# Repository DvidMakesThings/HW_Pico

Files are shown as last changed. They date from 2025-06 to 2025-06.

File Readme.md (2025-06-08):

# RePico

RePico is a custom-designed, feature-enhanced Raspberry Pi Pico-compatible board built for serious embedded developers. It keeps full compatibility with the RP2040 ecosystem while upgrading key components for cleaner analog performance, improved configurability, and professional-grade layout.

<p align="center">
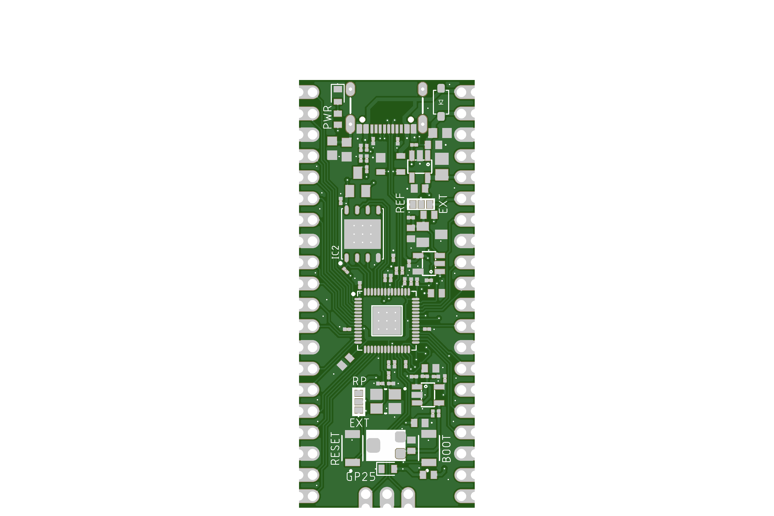
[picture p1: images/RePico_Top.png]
RePico Top
    
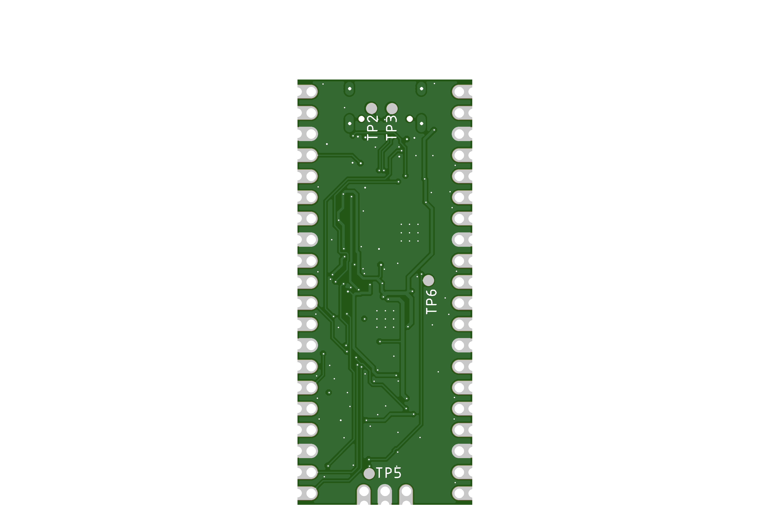
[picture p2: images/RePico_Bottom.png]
RePico Bottom
    
</p>

---

## 🔧 Key Hardware Features

- **USB-C** connector instead of Micro-USB for modern connectivity.
- **Low-noise 3.3V power supply** using `MIC5504-3.3YM5` 3.3V 300mA LDO (replaces noisy SMPS).
- **Selectable ADC Vref** via jumper:
  - External Vref input.
  - Internal precision 3.0V reference using `LM4040` + buffered by `MCP6001RT-I/OT`.
- **Selectable Vcore Supply** via jumper:
  - Use internal RP2040 regulator.
  - Or use onboard external 1.1V regulator based on `AP7335-WG-7` with adjustable output.
- **Adjustable Vcore Tuning** with trimpot-based feedback:

| Trimpot Resistance | Vcore Output |
|---|---|
| 25k (max) | ~1.00 V |
| 12.5k (mid) | ~1.18 V |
| 0 Ω (min) | ~1.24 V |

- **128Mbit (16MB) QSPI Flash** — 4x more than the standard Pico.
- **RESET** and **BOOT** buttons included onboard.
- **4-layer impedance-controlled PCB** for signal integrity.

---

## PCB Stackup

- **Total Layers:** 4
- **Finished Thickness:** ~1.56 mm ±10%
- **Outer Copper Weight:** 1 oz
- **Inner Copper Weight:** 0.5 oz
- **Material:** JLC04161H-3313 (FR4)

### Layer Stackup

| Layer | Description | Material | Thickness (mm) |
|---|---|---|---|
| L1 | Signal (Top) | Outer Copper 1 oz | 0.0350 |
| | Prepreg | 3313 RC57%, 4.2 mil | 0.0994 |
| L2 | Internal Plane | Inner Copper 0.5 oz | 0.0152 |
| | Core | 1.3 mm H/HOZ with copper | 1.2650 |
| L3 | Internal Plane | Inner Copper 0.5 oz | 0.0152 |
| | Prepreg | 3313 RC57%, 4.2 mil | 0.0994 |
| L4 | Signal (Bottom) | Outer Copper 1 oz | 0.0350 |
| | **Total Thickness** | | **1.5588 mm**  |

---

## 📏 Controlled Impedance Configuration

| Impedance (Ω) | Type | Signal Layer | Top Ref | Bottom Ref | Trace Width (mm) | Trace Spacing (mm) | Trace to Copper (mm) |
|---|---|---|---|---|---|---|---|
| 50 | Coplanar Single Ended | L1 | / | L2 | 0.1486 | / | 0.2032 |
| 90 | Coplanar Differential | L1 | / | L2 | 0.1488 | 0.1778 | 0.2032 |
| 90 | Coplanar Differential | L4 | L3 | / | 0.1488 | 0.1778 | 0.2032 |
| 50 | Coplanar Single Ended | L4 | L3 | / | 0.1486 | / | 0.2032 |

---

## 🧠 RP2040 Pinout Compatibility

All RP2040 GPIOs are exposed through 2.54mm castellated headers, maintaining full compatibility with the original Raspberry Pi Pico pinout. 

---

## Misc: Core Voltage & Overclocking

To overclock the MCU, it's possible to supply more than 1.1 V to the core.  
By default, **external core voltage generation** is enabled using the **AP7335-WG-7**, which is activated via **J1**.  
The output voltage is set by adjusting the **R1 trimpot**.

> ⚠️ It is safe — the voltage range is limited by design and cannot damage the MCU.

### Voltage Range (Set by Divider)

| R1 (Trimpot) | Total Resistance (R28 + R1) | VOUT (approx) |
|---|---|---|
| 25 kΩ (max)  | 47 kΩ | 1.02 V |
| 12.5 kΩ | 34.5 kΩ | 1.14 V |
| 0 Ω (min) | 22 kΩ | 1.22 V |

### Use Cases

- **Low Power Mode:** R1 = 25 kΩ → ~1.02 V  
- **Default / Safe:** R1 = 12.5 kΩ → ~1.14 V  
- **High Performance / Overclocking:** R1 = 0 Ω → ~1.22 V  

### VOUT Behavior Across Temperatures and Trim Settings

The AP7335-WG-7 regulator is affected by temperature-dependent reference voltage (VREF), output voltage accuracy, and resistor tolerances.  
This section outlines the **worst-case VOUT values** at cold, normal, and hot temperatures, across all trimpot settings.

> ⚙️ **Calculation Parameters:**
> - VOUT Accuracy: ±2% (from AP7335-WG-7 datasheet)
> - VREF Variation: Based on VREF vs. Temperature graph  
>   - −50 °C → 0.89 V  
>   - 25 °C → 0.80 V  
>   - 125 °C → 0.782 V
> - Resistors used: 1% tolerance (R27 = 12 kΩ, R28 = 22 kΩ, R1 = 0–25 kΩ trimpot)

The RP2040's **absolute maximum core voltage is 1.3 V** — values exceeding this may cause damage.

---

### ❄️ Cold (–50 °C, VREF = 0.89 V)

**Max Trim (R1 = 25 kΩ, Rb = 47 kΩ)**  
VOUT: **1.090 V – 1.144 V** ✅ Safe

**Mid Trim (R1 = 12.5 kΩ, Rb = 34.5 kΩ)**  
VOUT: **1.170 V – 1.230 V** ✅ Safe

**Min Trim (R1 = 0 Ω, Rb = 22 kΩ)**  
VOUT: **1.339 V – 1.413 V** ❌ Danger – exceeds RP2040 1.3 V limit

---

### 🌤️ Normal (25 °C, VREF = 0.80 V)

**Max Trim (R1 = 25 kΩ, Rb = 47 kΩ)**  
VOUT: **0.980 V – 1.029 V** ✅ Safe

**Mid Trim (R1 = 12.5 kΩ, Rb = 34.5 kΩ)**  
VOUT: **1.051 V – 1.106 V** ✅ Safe

**Min Trim (R1 = 0 Ω, Rb = 22 kΩ)**  
VOUT: **1.201 V – 1.265 V** ✅ Safe

---

### 🔥 Hot (125 °C, VREF = 0.782 V)

**Max Trim (R1 = 25 kΩ, Rb = 47 kΩ)**  
VOUT: **0.958 V – 1.005 V** ✅ Safe

**Mid Trim (R1 = 12.5 kΩ, Rb = 34.5 kΩ)**  
VOUT: **1.028 V – 1.082 V** ✅ Safe

**Min Trim (R1 = 0 Ω, Rb = 22 kΩ)**  
VOUT: **1.180 V – 1.243 V** ✅ Safe

## License
This project is licensed under the GPL-3.0 License. See the [LICENSE](LICENSE) file for details.

## Contact
For questions or feedback:
- Email: [dvidmakesthing@gmail.com](mailto:dvidmakesthing@gmail.com)
- GitHub: [DvidMakesThings](https://github.com/DvidMakesThings)

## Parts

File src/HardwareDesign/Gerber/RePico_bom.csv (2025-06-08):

Comment | Designator | Footprint | LCSC Part #
 | IC2 | SON127P600X500X75-8N
1K 1% | R4 | 0201 | C270365
1K 1% | R5 | 0201 | C270365
1K 1% | R20 | 0402 | C11702
1K 1% | R21 | 0402 | C11702
1M 1% | R14 | 0603 | C22935
1nF 25V | C27 | 0201 | C7694325V
1uF 25V | C32 | 0402 | C52923
2.2uF 25V | C8 | 0402 | C385032
2.2uF 25V | C10 | 0402 | C385032
4.7K 1% | R6 | 0402 | C25900
4.7nF 50V | C22 | 0603 | C53987
4.7uF 25V | C30 | 0402 | C22367824
4.7uF 25V | C31 | 0402 | C22367824
5.1K 1% | R12 | 0201 | C274341
5.1K 1% | R13 | 0201 | C274341
10K 1% | R1 | 0201 | C473048
10K 1% | R8 | 0201 | C473048
10K 1% | R16 | 0201 | C473048
10K 1% | R17 | 0201 | C473048
12K 1% | R9 | 0201 | C270363
12MHz | X1 | WE-XTAL_CFPX-180 | C9002
15pF 50V | C14 | 0201 | C22374851
15pF 50V | C15 | 0201 | C22374851
22K 1% | R10 | 0201 | C474416
22uF 10V | C23 | 0603 | C60077
27R 1% | R2 | 0201 | C473051
27R 1% | R3 | 0201 | C473051
47uF 10V | C24 | 0805 | C6119904
50K | R7 | SMD_TRIMM | C913246
50K 1% | R11 | 0402 | C166559
100K 1% | R15 | 0201 | C270364
100K 1% | R18 | 0201 | C270364
100nF 25V | C1 | 0201 | C76939
100nF 25V | C2 | 0201 | C76939
100nF 25V | C3 | 0201 | C76939
100nF 25V | C4 | 0201 | C76939
100nF 25V | C5 | 0201 | C76939
100nF 25V | C6 | 0201 | C76939
100nF 25V | C7 | 0201 | C76939
100nF 25V | C9 | 0201 | C76939
100nF 25V | C11 | 0201 | C76939
100nF 25V | C12 | 0201 | C76939
100nF 25V | C13 | 0201 | C76939
100nF 25V | C16 | 0201 | C76939
100nF 25V | C17 | 0201 | C76939
100nF 25V | C18 | 0201 | C76939
100nF 25V | C19 | 0201 | C76939
100nF 25V | C20 | 0201 | C76939
100nF 25V | C21 | 0201 | C76939
100nF 50V | C25 | 0402 | C307331
100nF 50V | C26 | 0402 | C307331
200K 1% | R19 | 0201 | C270357
AP7335-WG-7 | IC8 | SOT23-5 | C460382
B3U-1000P | BOOT | B3U-1000P | C231329
B3U-1000P | RESET | B3U-1000P | C231329
Blue | PWR | LED-0603 | C965807
DMG1012T | T1 | SOT23 | C2830301
DNI | J2 | R0201
Green | GP25 | LED-0603 | C965804
JUMPER-3 | J1 J3 | JUMPER-3
LM4040B30FTA | REF1 | SOT23 | C460604
MBR120VLSFT1G | D1 | SOD-123 | C223608
MCP6001RT-I/OT | IC5 | SOT23-5 | C154973
MIC5504-3.3YM5 | IC3 | SOT23-5 | C41348078
RP2040 | IC1 | QFN56 | C2040
SP0503BAHTG | ESD1 | SOT143 | C3040626
USB-TYPE-C-018 | USB1 | USB-C | C2927038
TPB1 27 | TP2 | B1 27
TPB1 27 | TP3 | B1 27
TPB1 27 | TP5 | B1 27
TPB1 27 | TP6 | B1 27

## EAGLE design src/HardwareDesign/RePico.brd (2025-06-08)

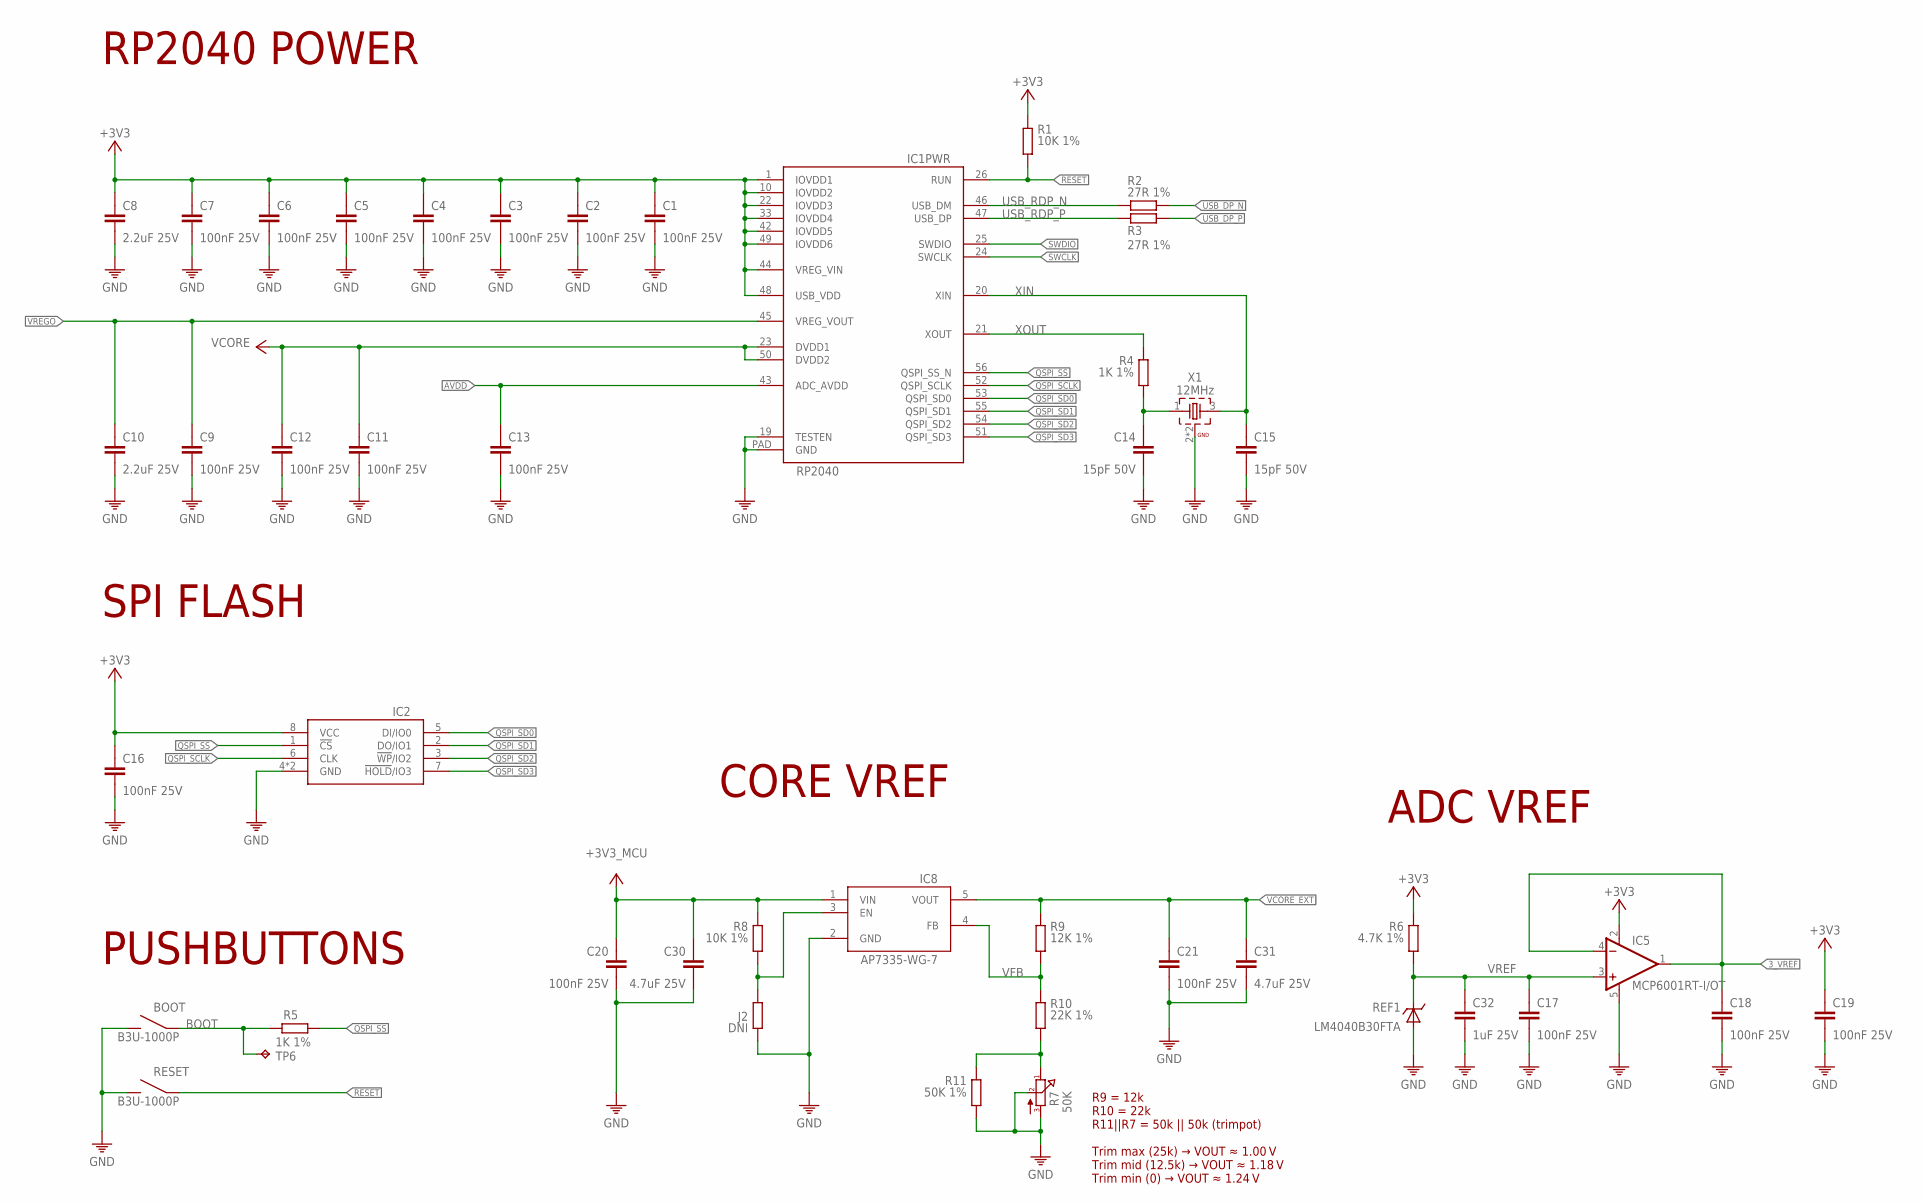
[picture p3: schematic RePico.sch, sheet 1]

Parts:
BOOT: B3U-1000P
C1, C2, C3, C4, C5, C6, C7, C9, C11, C12, C13, C16, C17, C18, C19, C20, C21: 100nF 25V; 0201
C8, C10: 2.2uF 25V; 0402
C14, C15: 15pF 50V; 0201
C30, C31: 4.7uF 25V; 0402
C32: 1uF 25V; 0402
IC1: RP2040; QFN56
IC2: W25Q128JVP; SON127P600X500X75-8N
IC5: MCP6001RT-I/OT; SOT23-5
IC8: AP7335-WG-7; SOT23-5
J2: DNI; R0201
R1, R8: 10K 1%; 0201
R2, R3: 27R 1%; 0201
R4, R5: 1K 1%; 0201
R6: 4.7K 1%; 0402
R7: 50K; SMD_TRIMM
R9: 12K 1%; 0201
R10: 22K 1%; 0201
R11: 50K 1%; 0402
REF1: LM4040B30FTA; SOT23
RESET: B3U-1000P
TP6: TPB1,27; B1,27
X1: 12MHz; WE-XTAL_CFPX-180

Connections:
3_VREF: C18.1, IC5.1 (OUT), IC5.4 (-IN); also elsewhere on the board
+3V3: C1.1, C2.1, C3.1, C4.1, C5.1, C6.1, C7.1, C8.1, C16.1, C19.1, IC1.1 (IOVDD1), IC1.10 (IOVDD2), IC1.22 (IOVDD3), IC1.33 (IOVDD4), IC1.42 (IOVDD5), IC1.44 (VREG_VIN), IC1.48 (USB_VDD), IC1.49 (IOVDD6), IC2.8 (VCC), IC5.2 (V+), R1.1, R6.1; also elsewhere on the board
+3V3_MCU: C20.1, C30.1, IC8.1 (VIN), R8.1
AVDD: C13.1, IC1.43 (ADC_AVDD); also elsewhere on the board
BOOT: BOOT.1, R5.1, TP6.TP
FBTRIM: R7.1, R10.2, R11.1
GND: BOOT.2, C1.2, C2.2, C3.2, C4.2, C5.2, C6.2, C7.2, C8.2, C9.2, C10.2, C11.2, C12.2, C13.2, C14.2, C15.2, C16.2, C17.2, C18.2, C19.2, C20.2, C21.2, C30.2, C31.2, C32.2, IC1.19 (TESTEN), IC1.PAD (GND), IC2.4 (GND), IC2.PAD (GND), IC5.5 (V-), IC8.2 (GND), J2.2, R7.2, R7.3, R11.2, REF1.2 (A), REF1.3 (A), RESET.2, X1.2 (GND), X1.4 (GND); also elsewhere on the board
unnamed: IC8.3 (EN), J2.1, R8.2
QSPI_SCLK: IC1.52 (QSPI_SCLK), IC2.6 (CLK)
QSPI_SD0: IC1.53 (QSPI_SD0), IC2.5 (DI/IO0)
QSPI_SD1: IC1.55 (QSPI_SD1), IC2.2 (DO/IO1)
QSPI_SD2: IC1.54 (QSPI_SD2), IC2.3 (!WP!/IO2)
QSPI_SD3: IC1.51 (QSPI_SD3), IC2.7 (!HOLD!/IO3)
QSPI_SS: IC1.56 (QSPI_SS_N), IC2.1 (!CS), R5.2
RESET: IC1.26 (RUN), R1.2, RESET.1; also elsewhere on the board
SWCLK: IC1.24 (SWCLK); also elsewhere on the board
SWDIO: IC1.25 (SWDIO); also elsewhere on the board
USB_DP_N: R2.2; also elsewhere on the board
USB_DP_P: R3.2; also elsewhere on the board
USB_RDP_N: IC1.46 (USB_DM), R2.1
USB_RDP_P: IC1.47 (USB_DP), R3.1
VCORE: C11.1, C12.1, IC1.23 (DVDD1), IC1.50 (DVDD2); also elsewhere on the board
VCORE_EXT: C21.1, C31.1, IC8.5 (VOUT), R9.1; also elsewhere on the board
VFB: IC8.4 (FB), R9.2, R10.1
VREF: C17.1, C32.1, IC5.3 (+IN), R6.2, REF1.1 (C)
VREGO: C9.1, C10.1, IC1.45 (VREG_VOUT); also elsewhere on the board
XIN: C15.1, IC1.20 (XIN), X1.3 (2)
XOUT: IC1.21 (XOUT), R4.1
XO_R: C14.1, R4.2, X1.1

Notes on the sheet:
RP2040 POWER
SPI FLASH
PUSHBUTTONS
ADC VREF
CORE VREF
R9 = 12k R10 = 22k R11||R7 = 50k || 50k (trimpot) Trim max (25k) → VOUT ≈ 1.00 V Trim mid (12.5k) → VOUT ≈ 1.18 V Trim min (0) → VOUT ≈ 1.24 V

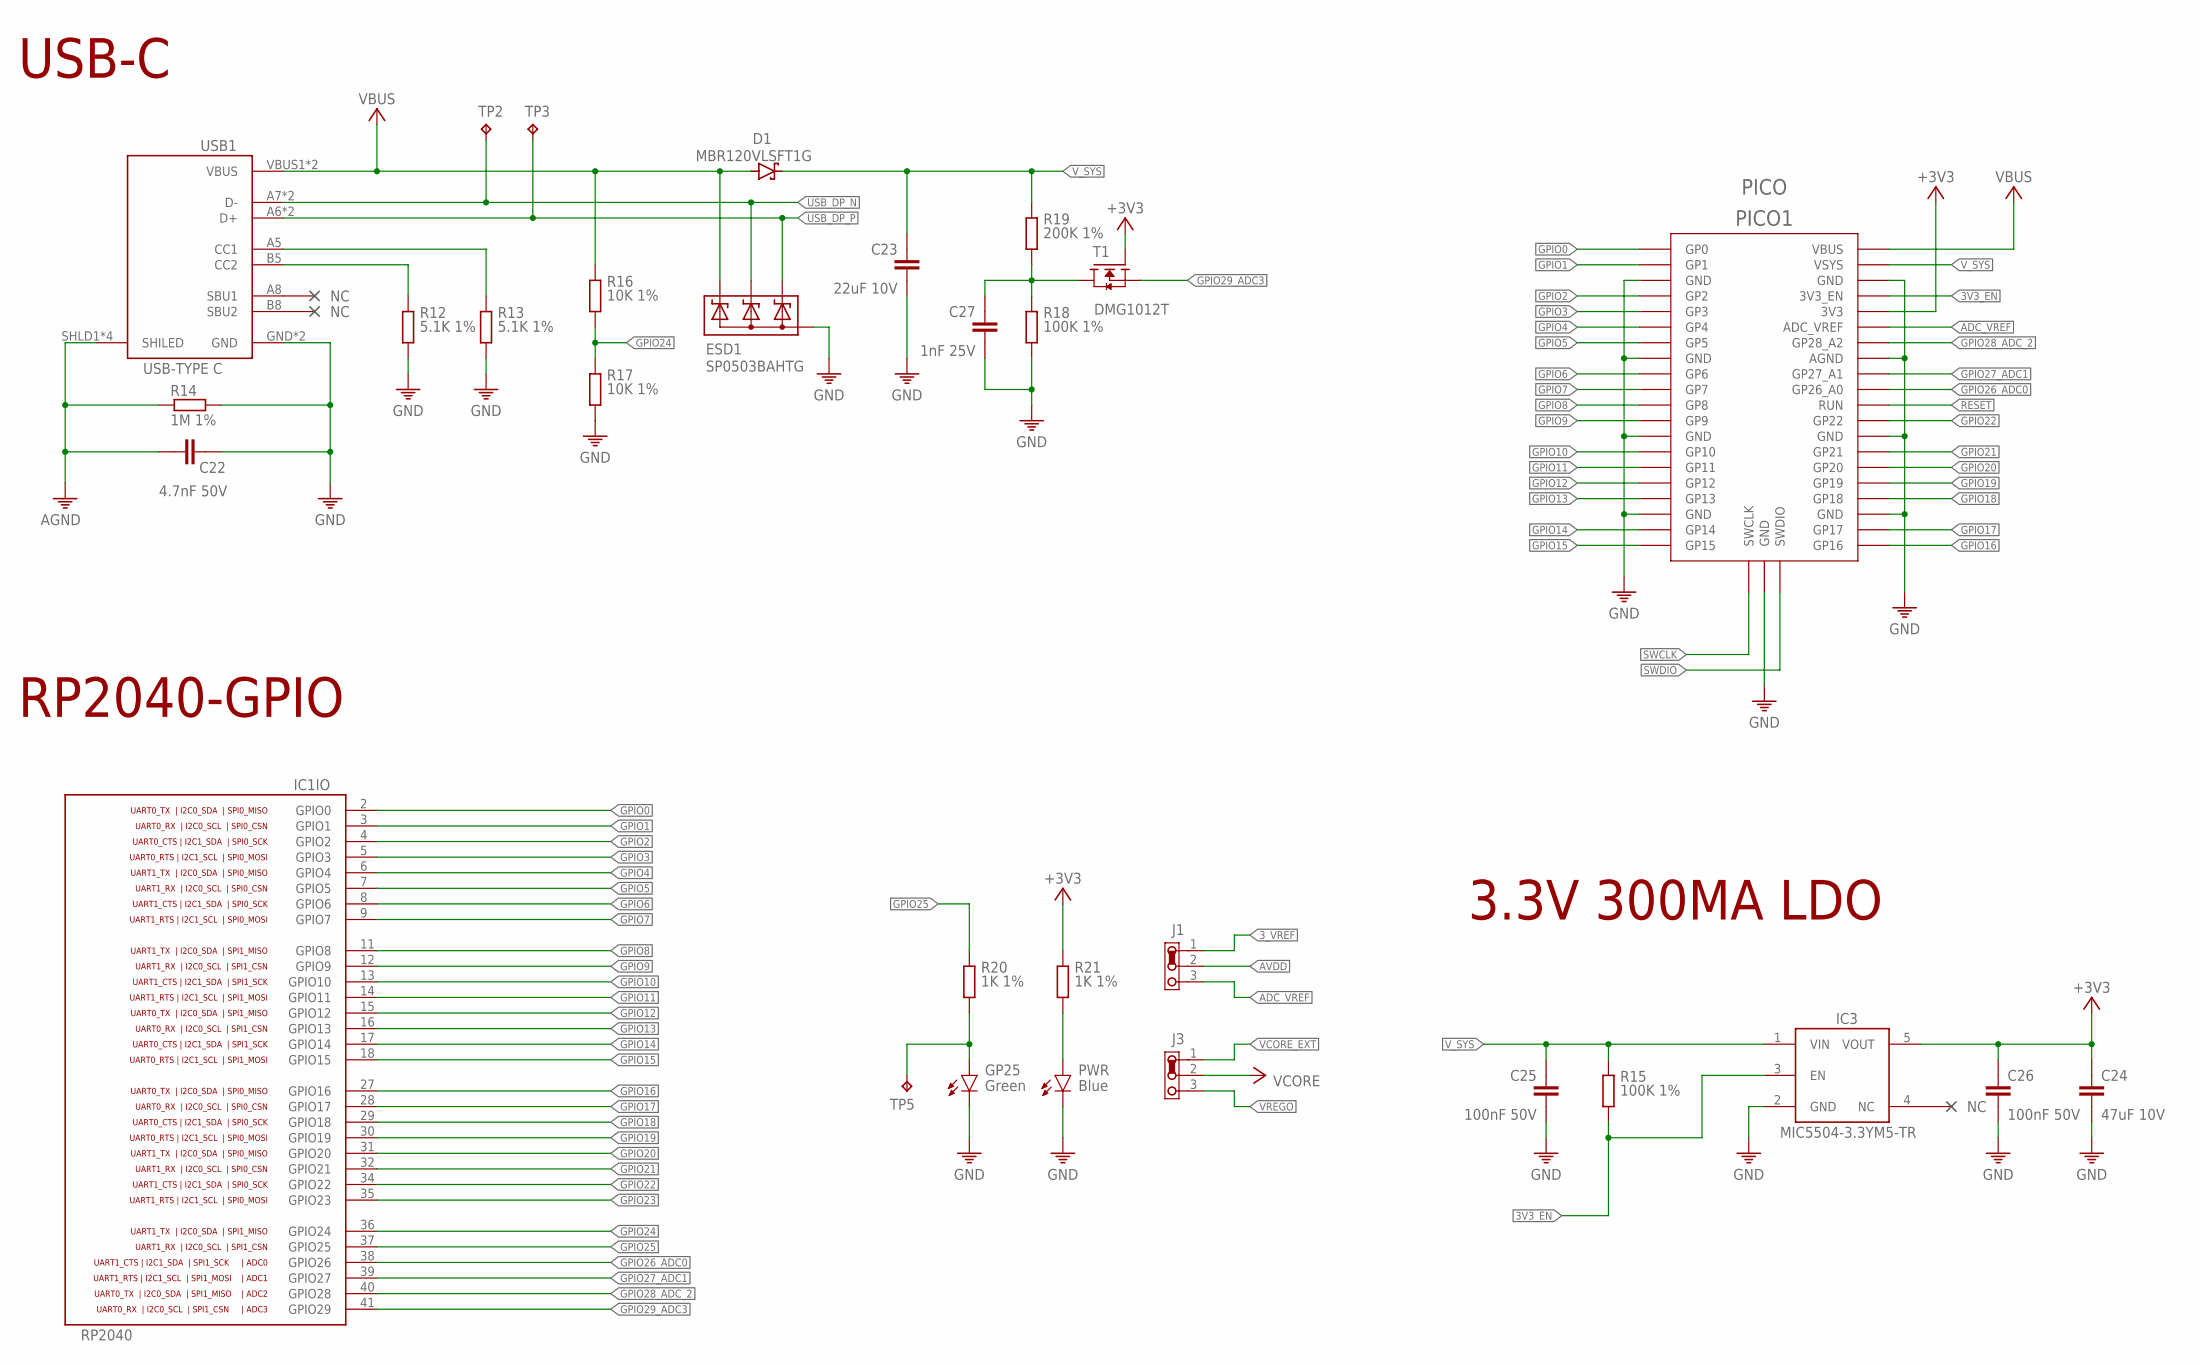
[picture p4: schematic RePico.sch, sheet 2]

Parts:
C22: 4.7nF 50V; 0603
C23: 22uF 10V; 0603
C24: 47uF 10V; 0805
C25, C26: 100nF 50V; 0402
C27: 1nF 25V; 0201
D1: MBR120VLSFT1G; SOD-123
ESD1: SP0503BAHTG; SOT143
GP25: Green; LED-0603
IC1: RP2040; QFN56
IC3: MIC5504-3.3YM5; SOT23-5
J1, J3: JUMPER-3
PICO1: PICO
PWR: Blue; LED-0603
R12, R13: 5.1K 1%; 0201
R14: 1M 1%; 0603
R15, R18: 100K 1%; 0201
R16, R17: 10K 1%; 0201
R19: 200K 1%; 0201
R20, R21: 1K 1%; 0402
T1: DMG1012T; SOT23
TP2, TP3, TP5: TPB1,27; B1,27
USB1: USB-TYPE-C-018; USB-C

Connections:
3V3_EN: IC3.3 (EN), PICO1.3V3_EN, PICO1.3VE (3V3_EN), R15.2
3_VREF: J1.1; also elsewhere on the board
+3V3: C24.1, C26.1, IC3.5 (VOUT), PICO1.3V (3V3), PICO1.3V3, R21.1, T1.1 (G); also elsewhere on the board
ADC_VREF: J1.3, PICO1.ADC_VREF, PICO1.AVR (ADC_VREF)
AGND: C22.1, R14.1, USB1.SHLD1 (SHILED), USB1.SHLD2 (SHILED), USB1.SHLD3 (SHILED), USB1.SHLD4 (SHILED)
AVDD: J1.2; also elsewhere on the board
GND: C22.2, C23.2, C24.2, C25.2, C26.2, C27.2, ESD1.1 (A), GP25.C, IC3.2 (GND), PICO1.AGN (AGND), PICO1.AGND, PICO1.G@1 (GND), PICO1.G@2 (GND), PICO1.G@3 (GND), PICO1.G@4 (GND), PICO1.G@5 (GND), PICO1.G@6 (GND), PICO1.G@7 (GND), PICO1.G@8 (GND), PICO1.GND@1 (GND), PICO1.GND@2 (GND), PICO1.GND@3 (GND), PICO1.GND@4 (GND), PICO1.GND@5 (GND), PICO1.GND@6 (GND), PICO1.GND@7 (GND), PICO1.GND@8 (GND), PWR.C, R12.2, R13.2, R14.2, R17.2, R18.2, USB1.GND, USB1.GND2 (GND); also elsewhere on the board
GPIO0: IC1.2 (GPIO0), PICO1.0 (GP0), PICO1.GP0
GPIO1: IC1.3 (GPIO1), PICO1.1 (GP1), PICO1.GP1
GPIO2: IC1.4 (GPIO2), PICO1.2 (GP2), PICO1.GP2
GPIO3: IC1.5 (GPIO3), PICO1.3 (GP3), PICO1.GP3
GPIO4: IC1.6 (GPIO4), PICO1.4 (GP4), PICO1.GP4
GPIO5: IC1.7 (GPIO5), PICO1.5 (GP5), PICO1.GP5
GPIO6: IC1.8 (GPIO6), PICO1.6 (GP6), PICO1.GP6
GPIO7: IC1.9 (GPIO7), PICO1.7 (GP7), PICO1.GP7
GPIO8: IC1.11 (GPIO8), PICO1.8 (GP8), PICO1.GP8
GPIO9: IC1.12 (GPIO9), PICO1.9 (GP9), PICO1.GP9
GPIO10: IC1.13 (GPIO10), PICO1.10 (GP10), PICO1.GP10
GPIO11: IC1.14 (GPIO11), PICO1.11 (GP11), PICO1.GP11
GPIO12: IC1.15 (GPIO12), PICO1.12 (GP12), PICO1.GP12
GPIO13: IC1.16 (GPIO13), PICO1.13 (GP13), PICO1.GP13
GPIO14: IC1.17 (GPIO14), PICO1.14 (GP14), PICO1.GP14
GPIO15: IC1.18 (GPIO15), PICO1.15 (GP15), PICO1.GP15
GPIO16: IC1.27 (GPIO16), PICO1.16 (GP16), PICO1.GP16
GPIO17: IC1.28 (GPIO17), PICO1.17 (GP17), PICO1.GP17
GPIO18: IC1.29 (GPIO18), PICO1.18 (GP18), PICO1.GP18
GPIO19: IC1.30 (GPIO19), PICO1.19 (GP19), PICO1.GP19
GPIO20: IC1.31 (GPIO20), PICO1.20 (GP20), PICO1.GP20
GPIO21: IC1.32 (GPIO21), PICO1.21 (GP21), PICO1.GP21
GPIO22: IC1.34 (GPIO22), PICO1.22 (GP22), PICO1.GP22
GPIO23: IC1.35 (GPIO23)
GPIO24: IC1.36 (GPIO24), R16.2, R17.1
GPIO25: IC1.37 (GPIO25), R20.1
GPIO26_ADC0: IC1.38 (GPIO26), PICO1.26 (GP26_A0), PICO1.GP26_A0
GPIO27_ADC1: IC1.39 (GPIO27), PICO1.27 (GP27_A1), PICO1.GP27_A1
GPIO28_ADC_2: IC1.40 (GPIO28), PICO1.28 (GP28_A2), PICO1.GP28_A2
GPIO29_ADC3: IC1.41 (GPIO29), T1.2 (S)
unnamed: R13.1, USB1.A5 (CC1)
unnamed: R12.1, USB1.B5 (CC2)
unnamed: C27.1, R18.1, R19.2, T1.3 (D)
unnamed: GP25.A, R20.2, TP5.TP
unnamed: PWR.A, R21.2
RESET: PICO1.R (RUN), PICO1.RUN; also elsewhere on the board
SWCLK: PICO1.SWC (SWCLK), PICO1.SWCLK; also elsewhere on the board
SWDIO: PICO1.SWD (SWDIO), PICO1.SWDIO; also elsewhere on the board
USB_DP_N: ESD1.3 (C2), TP2.TP, USB1.A7 (D-), USB1.B7 (D-); also elsewhere on the board
USB_DP_P: ESD1.2 (C1), TP3.TP, USB1.A6 (D+), USB1.B6 (D+); also elsewhere on the board
VBUS: D1.A, ESD1.4 (C3), PICO1.VBU (VBUS), PICO1.VBUS, R16.1, USB1.VBUS1 (VBUS), USB1.VBUS2 (VBUS)
VCORE: J3.2; also elsewhere on the board
VCORE_EXT: J3.1; also elsewhere on the board
VREGO: J3.3; also elsewhere on the board
V_SYS: C23.1, C25.1, D1.C, IC3.1 (VIN), PICO1.VSY (VSYS), PICO1.VSYS, R15.1, R19.1

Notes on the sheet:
USB-C
RP2040-GPIO
3.3V 300MA LDO

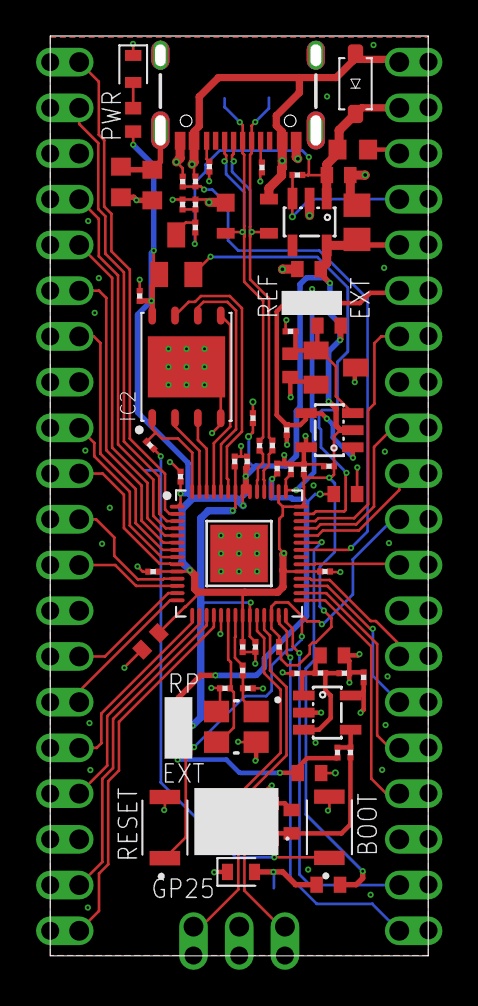
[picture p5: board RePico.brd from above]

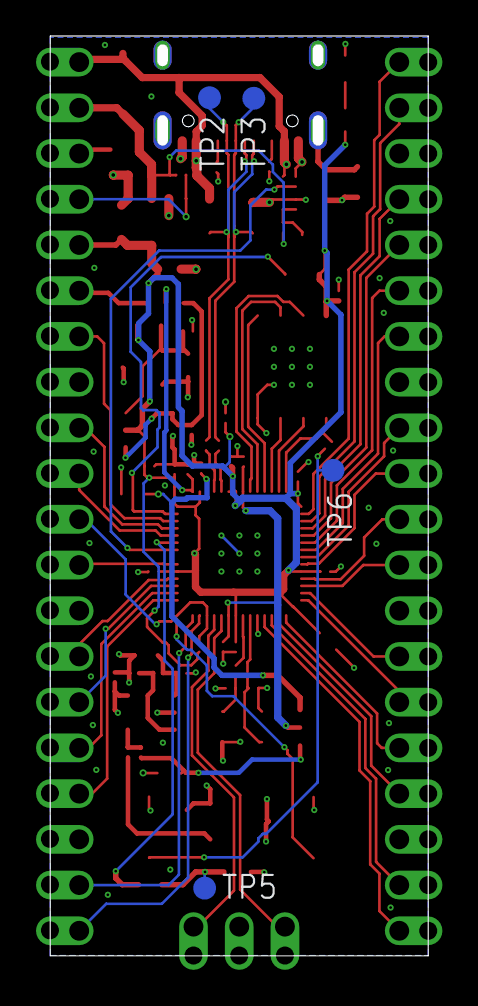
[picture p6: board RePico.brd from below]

Board: 4 copper layers, 21.0 x 51.1 mm, 74 parts (4 on the bottom side), 68 nets.

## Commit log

2025-06-08 initial creation
    [RePico.brd, RePico.sch, RePico_bom.csv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]
2025-06-08 add gerbers
    [RePico_bom.csv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]
